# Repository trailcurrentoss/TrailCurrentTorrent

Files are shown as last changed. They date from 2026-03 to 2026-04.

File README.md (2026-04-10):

# TrailCurrent Torrent

<p align="center">
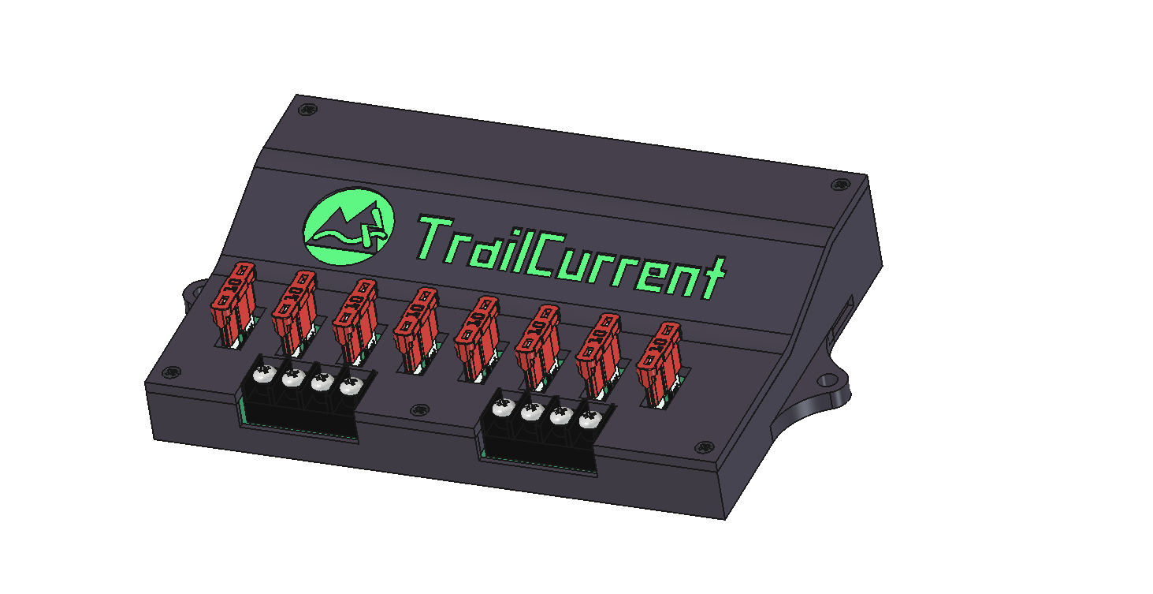
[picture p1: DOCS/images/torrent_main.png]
TrailCurrent Torrent
  
</p>

CAN-controlled 8-channel PWM power distribution module for vehicle lighting and accessory control with OTA firmware update capability and mDNS self-discovery. Up to 3 Torrent modules can operate on the same CAN bus, each with a unique address and CAN IDs. Part of the [TrailCurrent](https://trailcurrent.com) open-source vehicle platform.

## Hardware Overview

- **Microcontroller:** ESP32 (WROOM32)
- **Function:** 8-channel PWM lighting/accessory controller with CAN bus interface
- **Key Features:**
  - 8 independent MOSFET-driven PWM outputs (0-255 brightness)
  - CAN bus communication at 500 kbps
  - Up to 3 modules on the same bus via compile-time `TORRENT_ADDRESS` (0-2)
  - Individual and master on/off/brightness control
  - Animated light sequences (startup, interior, exterior)
  - Over-the-air (OTA) firmware updates via WiFi
  - mDNS self-discovery for automatic registration with Headwaters
  - WiFi credentials provisioned dynamically over CAN bus
  - Hierarchical PCB schematic design (5 sheets)

## Hardware Requirements

### Components

- **Microcontroller:** ESP32 development board
- **CAN Transceiver:** Vehicle CAN bus interface (TX: GPIO 15, RX: GPIO 13)
- **MOSFET Drivers:** 8 channels for PWM output switching
- **DIP Switches:** Configuration switches

### Pin Connections

**PWM Outputs:**

| GPIO | Function |
|---|---|
| 32 | Output 1 |
| 33 | Output 2 |
| 26 | Output 3 |
| 14 | Output 4 |
| 4 | Output 5 |
| 17 | Output 6 |
| 19 | Output 7 |
| 23 | Output 8 |

### KiCAD Library Dependencies

This project uses the consolidated [TrailCurrentKiCADLibraries](https://github.com/trailcurrentoss/TrailCurrentKiCADLibraries).

**Setup:**

```bash
# Clone the library
git clone git@github.com:trailcurrentoss/TrailCurrentKiCADLibraries.git

# Set environment variables (add to ~/.bashrc or ~/.zshrc)
export TRAILCURRENT_SYMBOL_DIR="/path/to/TrailCurrentKiCADLibraries/symbols"
export TRAILCURRENT_FOOTPRINT_DIR="/path/to/TrailCurrentKiCADLibraries/footprints"
export TRAILCURRENT_3DMODEL_DIR="/path/to/TrailCurrentKiCADLibraries/3d_models"
```

See [KICAD_ENVIRONMENT_SETUP.md](https://github.com/trailcurrentoss/TrailCurrentKiCADLibraries/blob/main/docs/KICAD_ENVIRONMENT_SETUP.md) in the library repository for detailed setup instructions.

## Opening the Project

1. **Set up environment variables** (see Library Dependencies above)
2. **Open KiCAD:**
   ```bash
   kicad EDA/trailcurrent-torrent.kicad_pro
   ```
3. **Verify libraries load** - All symbol and footprint libraries should resolve without errors
4. **View 3D models** - Open PCB and press `Alt+3` to view the 3D visualization

### Schematic Sheets

The design uses a hierarchical schematic with dedicated sheets:
- **Root** - Top-level connections
- **Power** - Power distribution and regulation
- **CAN** - CAN bus transceiver interface
- **MCU** - ESP32 microcontroller and support circuits
- **MOSFETs** - 8-channel MOSFET driver outputs
- **DIP Switch** - Configuration switches

## Firmware

Built with [ESP-IDF](https://docs.espressif.com/projects/esp-idf/en/latest/esp32/) (Espressif IoT Development Framework) targeting the ESP32.

### Prerequisites

Install ESP-IDF v5.x following the [official guide](https://docs.espressif.com/projects/esp-idf/en/latest/esp32/get-started/).

### Build and Flash

```bash
# Set up ESP-IDF environment
source ~/esp/v5.5.2/esp-idf/export.sh

# First time: set chip target
idf.py set-target esp32

# Build firmware (default address 0)
idf.py build

# Build for a specific module address (0-2)
idf.py build -DTORRENT_ADDRESS=1

# Flash and monitor (serial)
idf.py -p /dev/ttyUSB0 flash monitor
```

### Multi-Instance Addressing

Up to 3 Torrent modules can share the same CAN bus. Each module is built with a unique address that determines its CAN IDs:

```bash
idf.py build                      # Address 0 (default)
idf.py build -DTORRENT_ADDRESS=1  # Address 1
idf.py build -DTORRENT_ADDRESS=2  # Address 2
```

Each address produces a firmware binary with unique CAN IDs (see CAN Bus Protocol below). Flash each binary to a different ESP32. At boot, the module logs its address and CAN IDs for verification.

#### Building All Variants

Use `build-all.sh` to build all 3 address variants in a single run:

```bash
./build-all.sh
```

This produces two binaries per address — one for OTA updates, one for the web flasher:

| File | Contents | Used By |
|---|---|---|
| `build/torrent_addr{N}.bin` | Application image only | Headwaters OTA (`deploy.sh`, `ota.js`), direct `curl` uploads |
| `build/torrent_addr{N}_merged.bin` | Bootloader + partition table + OTA data + application | Web flasher (full flash at 0x0) |

The two binary types exist because OTA and the web flasher write to different targets. Headwaters OTA sends the binary to the device's `/ota` HTTP endpoint, which calls `esp_ota_write` to write it to a single app partition. That function validates the image as an application — a merged binary starts with the bootloader instead of an app header, so it would fail validation. The web flasher writes the entire flash contents starting at offset 0x0, so it needs all partitions combined into one file.

#### Creating a GitHub Release

After building all variants, attach all 6 binaries (3 app-only + 3 merged) as release assets:

```bash
git tag -a v1.0.0 -m "Firmware release v1.0.0"
git push origin v1.0.0

gh release create v1.0.0 \
  build/torrent_addr0.bin \
  build/torrent_addr1.bin \
  build/torrent_addr2.bin \
  build/torrent_addr0_merged.bin \
  build/torrent_addr1_merged.bin \
  build/torrent_addr2_merged.bin \
  --repo trailcurrentoss/TrailCurrentTorrent \
  --title "v1.0.0" \
  --notes "Firmware release v1.0.0"
```

Both the Headwaters deployment system and the web flasher pull from GitHub releases. The web flasher matches `_merged.bin` files by name for full-flash use. The Headwaters deployment system (`fetch-firmware.sh`) downloads the app-only `torrent_addr{N}.bin` files for OTA delivery.

### OTA Firmware Update

After initial serial flash, firmware can be updated over WiFi:

1. **Provision WiFi credentials** via CAN bus (message ID 0x01)
2. **Trigger OTA mode** via CAN bus (message ID 0x00 with device MAC bytes)
3. **Upload firmware** via HTTP — always use the app-only binary (`torrent_addr{N}.bin`), never the merged binary:
   ```bash
   curl -X POST http://esp32-XXYYZZ.local/ota --data-binary @build/torrent_addr0.bin
   ```

The device enters OTA mode for 3 minutes, starts an HTTP server, and advertises via mDNS. After a successful upload it reboots into the new firmware. Dual OTA partitions provide rollback safety.

### mDNS Self-Discovery

Modules register themselves with the Headwaters controller:

1. **Provision WiFi credentials** via CAN bus (message ID 0x01)
2. **Send discovery trigger** via CAN bus (message ID 0x02, broadcast)
3. Module joins WiFi and advertises a `_trailcurrent._tcp` mDNS service with metadata:
   - `type=torrent` — module type
   - `addr=0` — module address (0-2, from `TORRENT_ADDRESS` build flag)
   - `canid=0x1B` — CAN status message ID (varies by address)
   - `fw=1.0.0` — firmware version
4. Headwaters confirms registration by calling `GET /discovery/confirm`
5. Module tears down WiFi and returns to normal CAN operation

Discovery can be triggered again on subsequent CAN 0x02 broadcasts. A module that is already running a discovery session ignores additional triggers until the current session completes or times out (3 minutes).

### Logging

Firmware uses the ESP-IDF logging system (`ESP_LOGI`, `ESP_LOGW`, `ESP_LOGE`). Log output is available on the serial monitor at 115200 baud.

Log verbosity can be configured at build time via `idf.py menuconfig` under **Component config > Log output**.

**WiFi Credentials:**
- WiFi credentials are provisioned dynamically via CAN bus (Message ID 0x01)
- Credentials are stored in NVS (non-volatile storage) and persist across reboots
- For standalone testing, credentials can be set manually via NVS

### CAN Bus Protocol

CAN IDs are computed as `BASE + TORRENT_ADDRESS`. The table below shows base IDs and per-instance values.

**Receive (Bus → Module):**

| Base ID | Addr 0 | Addr 1 | Addr 2 | Description |
|---|---|---|---|---|
| — | 0x00 | 0x00 | 0x00 | OTA update trigger (3 bytes: last 3 MAC bytes for device targeting) |
| — | 0x01 | 0x01 | 0x01 | WiFi credential provisioning (chunked SSID/password protocol) |
| — | 0x02 | 0x02 | 0x02 | Discovery trigger (broadcast, no payload) |
| — | 0x04 | 0x04 | 0x04 | Version report on boot: `[mac3, mac4, mac5, major, minor, patch]` |
| 0x15 | 0x15 | 0x16 | 0x17 | Set brightness (byte 0 = channel 0-7, byte 1 = PWM value 0-255) |
| 0x18 | 0x18 | 0x19 | 0x1A | Toggle channel on/off (byte 0 = channel 0-7, 8=all off/on, 9=all on) |
| 0x33 | 0x33 | 0x34 | 0x35 | Trigger light sequence (byte 0: 0=interior, 1=exterior) |

**Transmit (Module → Bus):**

| Base ID | Addr 0 | Addr 1 | Addr 2 | Interval | Description |
|---|---|---|---|---|---|
| 0x1B | 0x1B | 0x1C | 0x1D | 33 ms (30 Hz) | Status report — current PWM values for all 8 channels (8 bytes) |

### WiFi Credential Provisioning Protocol

WiFi credentials are sent over CAN in chunks (max 6 payload bytes per CAN frame):

| Step | data[0] | Payload | Description |
|---|---|---|---|
| 1 | 0x01 | ssid_len, pass_len, ssid_chunks, pass_chunks | Start message |
| 2 | 0x02 | chunk_index, up to 6 bytes | SSID chunk |
| 3 | 0x03 | chunk_index, up to 6 bytes | Password chunk |
| 4 | 0x04 | XOR checksum | End/commit message |

All messages are sent on CAN ID 0x01. A 5-second timeout resets the state machine if the sequence is interrupted.

## Manufacturing

- **PCB Files:** Ready for fabrication via standard PCB services (JLCPCB, OSH Park, etc.)
- **BOM Generation:** Export BOM from KiCAD schematic (Tools > Generate BOM)
- **JLCPCB Assembly:** See [BOM_ASSEMBLY_WORKFLOW.md](https://github.com/trailcurrentoss/TrailCurrentKiCADLibraries/blob/main/tools/BOM_ASSEMBLY_WORKFLOW.md) for detailed assembly workflow

## Project Structure

```
├── EDA/                          # KiCAD hardware design files
│   ├── trailcurrent-torrent.kicad_pro
│   ├── trailcurrent-torrent.kicad_sch  # Root schematic
│   ├── can.kicad_sch             # CAN subsystem
│   ├── mcu.kicad_sch             # MCU subsystem
│   ├── power.kicad_sch           # Power subsystem
│   ├── mosfets.kicad_sch         # 8-channel MOSFET drivers
│   ├── dip_switch.kicad_sch      # Configuration switches
│   └── trailcurrent-torrent.kicad_pcb  # PCB layout
├── CAD/                          # FreeCAD case design and 3D models
│   ├── trailcurrent-torrent-case.FCStd
│   └── TrailCurrentTorrent.3mf
├── main/                         # ESP-IDF firmware source
│   ├── main.c                    # App entry, LEDC PWM, TWAI CAN task, light sequences
│   ├── ota.h / ota.c             # OTA updates, WiFi management, credential provisioning
│   ├── discovery.h / discovery.c # mDNS self-discovery and Headwaters registration
│   ├── CMakeLists.txt            # Component build config
│   └── idf_component.yml         # ESP-IDF component dependencies
├── partitions.csv                # ESP32 flash partition layout (dual OTA)
├── sdkconfig.defaults            # ESP-IDF build defaults
├── build-all.sh                  # Build all 3 address variants (addr 0-2)
└── CMakeLists.txt                # Root ESP-IDF project config
```

## License

MIT License - See LICENSE file for details.

This is open source hardware. You are free to use, modify, and distribute these designs under the terms of the MIT license.

## Contributing

Improvements and contributions are welcome! Please submit issues or pull requests.

## Support

For questions about:
- **KiCAD setup:** See [KICAD_ENVIRONMENT_SETUP.md](https://github.com/trailcurrentoss/TrailCurrentKiCADLibraries/blob/main/docs/KICAD_ENVIRONMENT_SETUP.md)
- **Assembly workflow:** See [BOM_ASSEMBLY_WORKFLOW.md](https://github.com/trailcurrentoss/TrailCurrentKiCADLibraries/blob/main/tools/BOM_ASSEMBLY_WORKFLOW.md)

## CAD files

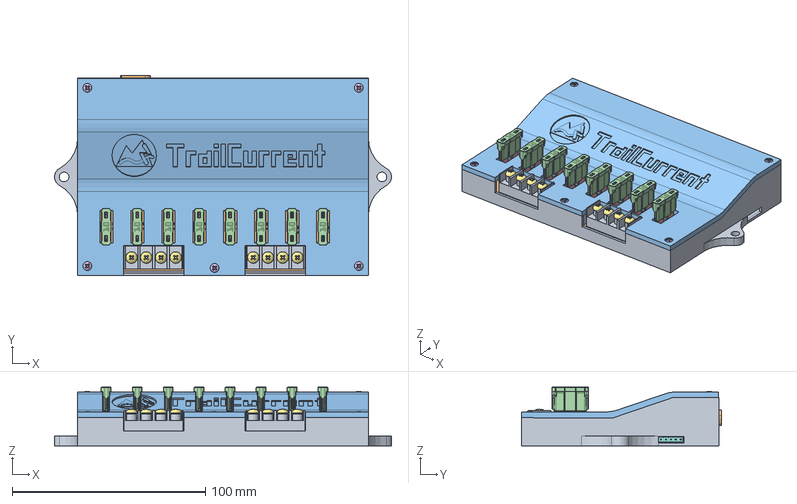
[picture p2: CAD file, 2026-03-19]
CAD/trailcurrent-torrent-case.FCStd
174.4 x 103.8 x 30.3 mm
BodyCaseBottom
Pcb_a65b
topPads_a65b
topTracks_a65b
botPads_a65b_cut
J5_Body_9aade6df98ed x 8
C4_C_1206_3216Metric_15ba0ad3e721 x 6
R8_R_1206_3216Metric_e07121ee4934 x 18
Q5_IRF4905STRLPBF_7185022933cc x 8
U5_DIP-4_W7.62mm_ebb48af450fe x 8
AP63203WU-7
AP63203WU-008
AP63203WU-009
AP63203WU-010
AP63203WU-011
AP63203WU-012
AP63203WU-013
AP63203WU-014
U1_ESP32-WROOM-32_2e14fae01c0c
U2_SOIC_8_39x49mm_P127mm_15ada4e996ee
FilletPin1
FilletPin2
J1_PinHeader_1x06_P254mm_Horizontal_2a81e018bd7b
J8_Body_1469dcacabcb x 2
XT60E-M
BodyContouredCover
ATOF Blade Fuse x 8
ATOF Blade Fuse001 x 8
2.5 mmx5-Screw x 5
3 mmx5-Screw x 8

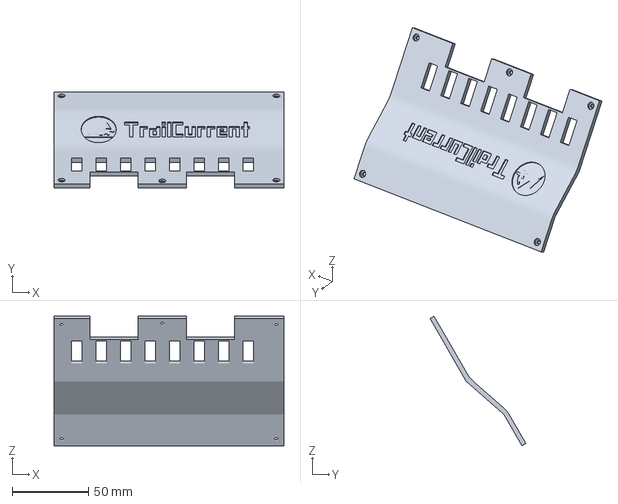
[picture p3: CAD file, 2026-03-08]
CAD/trailcurrent-torrent-case-BodyContouredCover.3mf
150.5 x 62.7 x 84.8 mm

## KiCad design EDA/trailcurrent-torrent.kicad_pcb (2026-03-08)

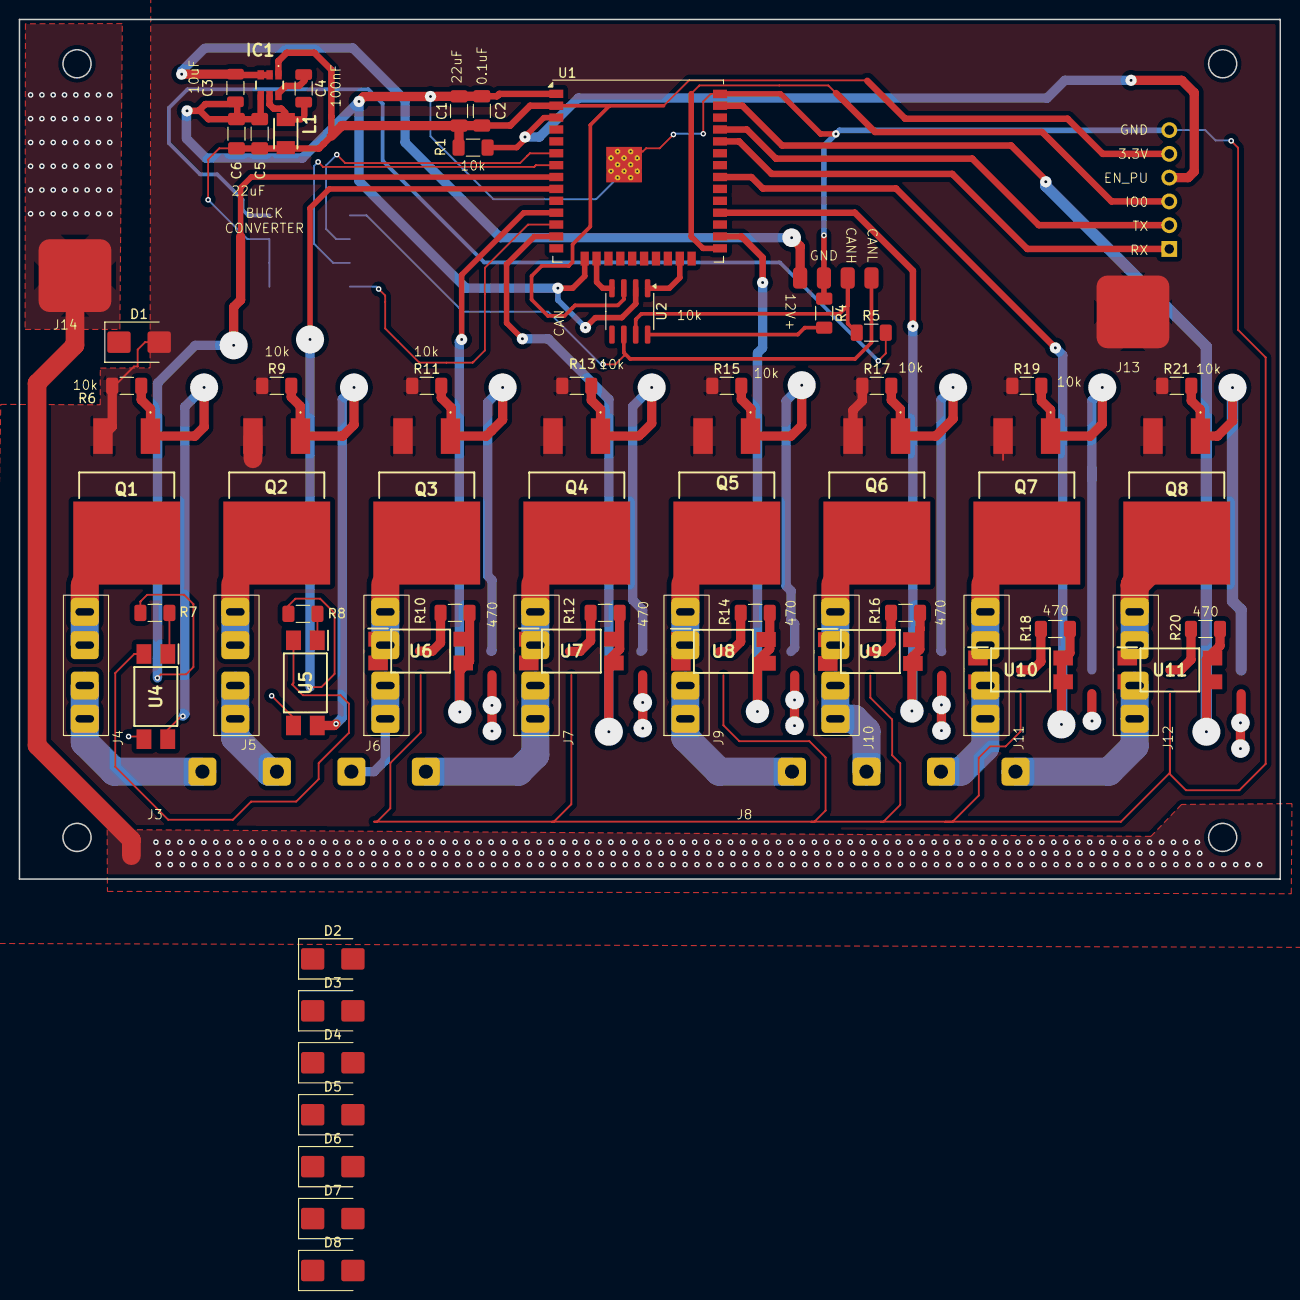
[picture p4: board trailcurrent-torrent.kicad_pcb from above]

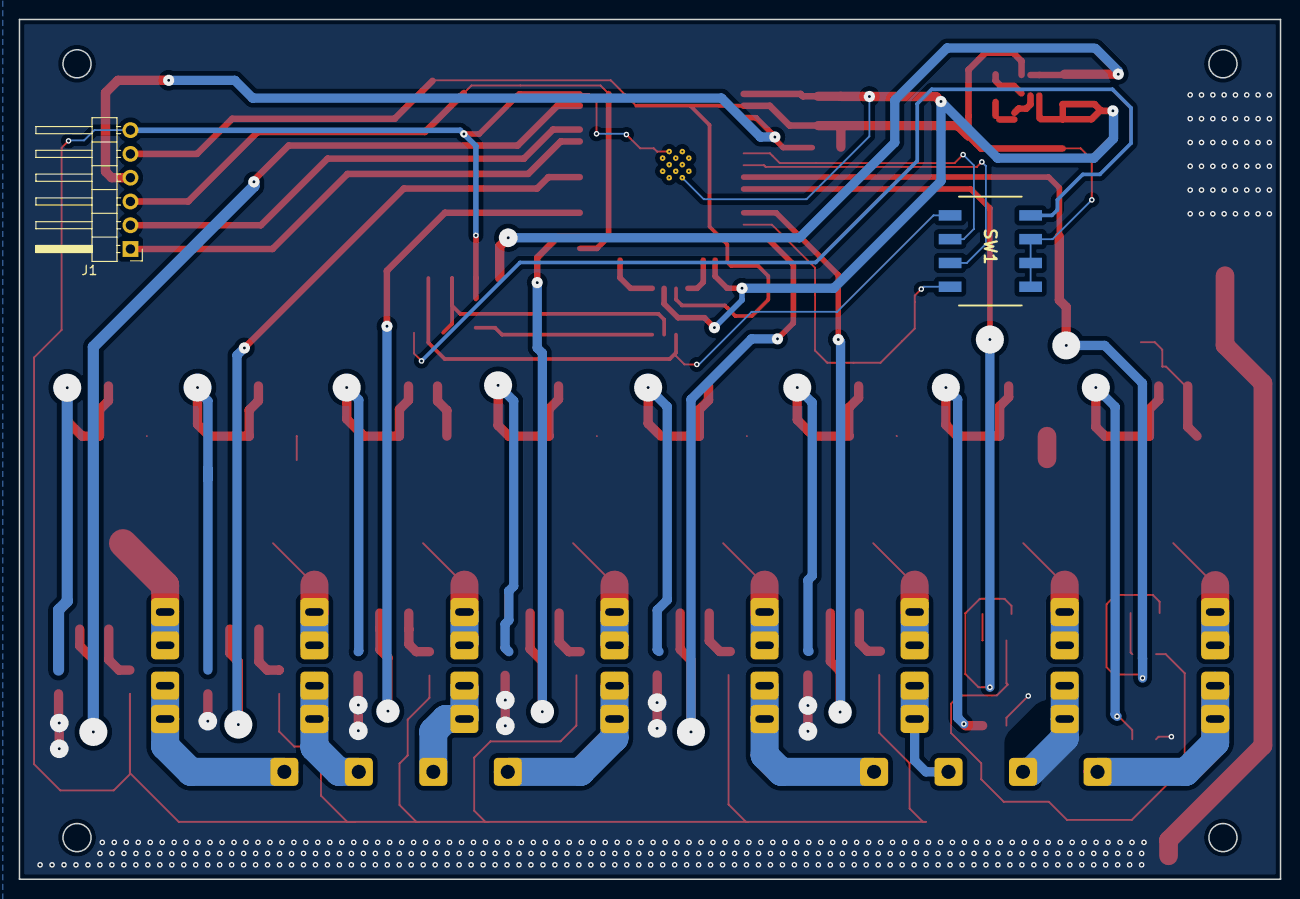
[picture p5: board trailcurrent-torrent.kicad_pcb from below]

Board: 2 copper layers, 134.7 x 91.9 mm, 68 parts (2 on the bottom side), 60 nets.

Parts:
C1, C5, C6: 22uF; C_1206_3216Metric_Pad1.33x1.80mm_HandSolder
C2: 0.1uF; C_1206_3216Metric_Pad1.33x1.80mm_HandSolder
C3: 10uF; C_1206_3216Metric
C4: 100nF; C_1206_3216Metric
D1, D2, D3, D4, D5, D6, D7, D8: SS54; D_SMB
IC1: AP63203WU-7; AP63203WU7
J1: Conn_01x06; PinHeader_1x06_P2.54mm_Horizontal
J2: Conn_01x04; CAN_PLUS_POWER
J3, J8: Conn_01x04; Screw_Terminal_1x04
J4, J5, J6, J7, J9, J10, J11, J12: Conn_01x04; Automotive_Fuse_Holder
J13, J14: Conn_01x01; TestPoint_7.77mmX7.77mm
L1: NLV32T-3R9J-EF (3.9uH); NLV32T-3R9J-EF
Q1, Q2, Q3, Q4, Q5, Q6, Q7, Q8: IRF4905STRLPBF
R1, R4, R6, R9, R11, R13, R15, R17, R19, R21: 10k; R_1206_3216Metric_Pad1.30x1.75mm_HandSolder
R5: 120; R_1206_3216Metric_Pad1.30x1.75mm_HandSolder
R7, R8, R10, R12, R14, R16, R18, R20: 470; R_1206_3216Metric_Pad1.30x1.75mm_HandSolder
SW1: SW_DIP_x04; SW_DIP_219-4LPST
U1: ESP32-WROOM-32; ESP32-WROOM-32U
U2: SN65HVD230; SOIC-8_3.9x4.9mm_P1.27mm
U4, U5, U6, U7, U8, U9, U10, U11: PC817; PC817X3CSP9F

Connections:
12V_OUT01: D1.1 (K), J4.3, J4.4, Q1.2 (D)
12V_OUT02: D2.1 (K), J5.3, J5.4, Q2.2 (D)
12V_OUT03: D3.1 (K), J6.3, J6.4, Q3.2 (D)
12V_OUT04: D4.1 (K), J7.3, J7.4, Q4.2 (D)
12V_OUT05: D5.1 (K), J9.3, J9.4, Q5.2 (D)
12V_OUT06: D6.1 (K), J10.3, J10.4, Q6.2 (D)
12V_OUT07: D7.1 (K), J11.3, J11.4, Q7.2 (D)
12V_OUT08: D8.1 (K), J12.3, J12.4, Q8.2 (D)
+3.3V: C1.1, C2.1, C5.1, C6.1, IC1.1 (FB), J1.5, L1.2, R1.1, SW1.5, SW1.6, SW1.7, U1.2 (VDD), U2.3 (VCC)
+12V: C3.1, IC1.2 (EN), IC1.3 (VIN), J2.1
+15V: D1.2 (A), D2.2 (A), D3.2 (A), D4.2 (A), D5.2 (A), D6.2 (A), D7.2 (A), D8.2 (A), J13.1, Q1.3 (S), Q2.3 (S), Q3.3 (S), Q4.3 (S), Q5.3 (S), Q6.3 (S), Q7.3 (S), Q8.3 (S), R6.1, R9.1, R11.1, R13.1, R15.1, R17.1, R19.1, R21.1
CANH: J2.3, R5.1, U2.7 (CANH)
CANL: J2.4, SW1.1, U2.6 (CANL)
CAN_RX: U1.16 (IO13), U2.4 (R)
CAN_TERM_CLOSED: R5.2, SW1.8
CAN_TX: U1.23 (IO15), U2.1 (D)
DEVICE01: R7.1, U1.8 (IO32)
DEVICE02: R8.1, U1.9 (IO33)
DEVICE03: R10.1, U1.11 (IO26)
DEVICE04: R12.1, U1.13 (IO14)
DEVICE05: R14.1, U1.26 (IO4)
DEVICE06: R16.1, U1.28 (IO17)
DEVICE07: R18.1, U1.31 (IO19)
DEVICE08: R20.1, U1.37 (IO23)
DEVICE_SELECTION01: SW1.2, U1.6 (IO34)
DEVICE_SELECTION02: SW1.3, U1.7 (IO35)
DEVICE_SELECTION03: SW1.4, U1.12 (IO27)
EN: J1.4, R1.2, U1.3 (EN)
ESP32_RX: J1.1, U1.34 (RXD0/IO3)
ESP32_TX: J1.2, U1.35 (TXD0/IO1)
GND: C1.2, C2.2, C3.2, C5.2, C6.2, IC1.4 (GND), J1.6, J2.2, R4.1, U1.1 (GND), U1.15 (GND), U1.38 (GND), U1.39 (GND), U2.2 (GND), U4.2, U5.2, U6.2, U7.2, U8.2, U9.2, U10.2, U11.2
GND1: J14.1, U4.3, U5.3, U6.3, U7.3, U8.3, U9.3, U10.3, U11.3
IO0: J1.3, U1.25 (IO0)
LOAD01: J3.1, J4.1, J4.2
LOAD02: J3.2, J5.1, J5.2
LOAD03: J3.3, J6.1, J6.2
LOAD04: J3.4, J7.1, J7.2
LOAD05: J8.1, J9.1, J9.2
LOAD06: J8.2, J10.1, J10.2
LOAD07: J8.3, J11.1, J11.2
LOAD08: J8.4, J12.1, J12.2
unnamed: C4.1, IC1.6 (BST)
unnamed: C4.2, IC1.5 (SW), L1.1
unnamed: Q1.1 (G), R6.2, U4.4
unnamed: Q2.1 (G), R9.2, U5.4
unnamed: Q3.1 (G), R11.2, U6.4
unnamed: Q4.1 (G), R13.2, U7.4
unnamed: Q5.1 (G), R15.2, U8.4
unnamed: Q6.1 (G), R17.2, U9.4
unnamed: Q7.1 (G), R19.2, U10.4
unnamed: Q8.1 (G), R21.2, U11.4
unnamed: R7.2, U4.1
unnamed: R8.2, U5.1
unnamed: R10.2, U6.1
unnamed: R12.2, U7.1
unnamed: R14.2, U8.1
unnamed: R16.2, U9.1
unnamed: R18.2, U10.1
unnamed: R20.2, U11.1
unnamed: R4.2, U2.8 (Rs)

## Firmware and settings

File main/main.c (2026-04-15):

#include "freertos/FreeRTOS.h"
#include "freertos/task.h"
#include "esp_log.h"
#include "wifi_config.h"
#include "ota.h"
#include "discovery.h"
#include "can_handler.h"
#include "pwm_output.h"

static const char *TAG = "torrent";

#ifndef TORRENT_ADDRESS
#define TORRENT_ADDRESS 0
#endif

void app_main(void)
{
    ESP_LOGI(TAG, "=== TrailCurrent Torrent (addr %d) ===", TORRENT_ADDRESS);
    ESP_LOGI(TAG, "8-Channel PWM Lighting Control Module");

    wifi_config_init();

    char ssid[33], password[64];
    if (wifi_config_load(ssid, sizeof(ssid), password, sizeof(password))) {
        ESP_LOGI(TAG, "WiFi credentials loaded (SSID: %s)", ssid);
    } else {
        ESP_LOGW(TAG, "No WiFi credentials — provision via CAN ID 0x01");
    }

    ota_init();
    discovery_init();

    ESP_LOGI(TAG, "Hostname: %s", wifi_config_get_hostname());

    pwm_output_init();

    ESP_ERROR_CHECK(can_handler_init());

    ESP_LOGI(TAG, "=== Setup Complete ===");

    xTaskCreatePinnedToCore(can_handler_task, "can_task", 4096, NULL, 5, NULL, 1);

    while (1) {
        vTaskDelay(pdMS_TO_TICKS(1000));
    }
}

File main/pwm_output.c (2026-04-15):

#include "pwm_output.h"

#include "driver/ledc.h"
#include "esp_log.h"
#include "freertos/FreeRTOS.h"
#include "freertos/task.h"

static const char *TAG = "pwm";

// =============================================================================
// Pin and LEDC configuration
// =============================================================================

static const int OUTPUT_PINS[NUM_OUTPUTS] = {
    32,  // OUTPUT01
    33,  // OUTPUT02
    26,  // OUTPUT03
    14,  // OUTPUT04
     4,  // OUTPUT05
    17,  // OUTPUT06
    19,  // OUTPUT07
    23,  // OUTPUT08
};

#define LEDC_TIMER      LEDC_TIMER_0
#define LEDC_MODE       LEDC_LOW_SPEED_MODE
#define LEDC_DUTY_RES   LEDC_TIMER_8_BIT   // 0-255
#define LEDC_FREQUENCY  5000               // 5 kHz

// =============================================================================
// Internal state
// =============================================================================

static uint8_t s_values[NUM_OUTPUTS] = {0};

// =============================================================================
// Public API
// =============================================================================

void pwm_output_init(void)
{
    ledc_timer_config_t timer_cfg = {
        .speed_mode      = LEDC_MODE,
        .duty_resolution = LEDC_DUTY_RES,
        .timer_num       = LEDC_TIMER,
        .freq_hz         = LEDC_FREQUENCY,
        .clk_cfg         = LEDC_AUTO_CLK,
    };
    ledc_timer_config(&timer_cfg);

    for (int i = 0; i < NUM_OUTPUTS; i++) {
        ledc_channel_config_t ch_cfg = {
            .gpio_num   = OUTPUT_PINS[i],
            .speed_mode = LEDC_MODE,
            .channel    = (ledc_channel_t)i,
            .timer_sel  = LEDC_TIMER,
            .duty       = 0,
            .hpoint     = 0,
        };
        ledc_channel_config(&ch_cfg);
    }

    ESP_LOGI(TAG, "LEDC PWM initialized: %d channels at %d Hz", NUM_OUTPUTS, LEDC_FREQUENCY);
}

void pwm_set(int channel, uint8_t duty)
{
    if (channel < 0 || channel >= NUM_OUTPUTS) return;
    s_values[channel] = duty;
    ledc_set_duty(LEDC_MODE, (ledc_channel_t)channel, duty);
    ledc_update_duty(LEDC_MODE, (ledc_channel_t)channel);
}

void pwm_set_all(uint8_t duty)
{
    for (int i = 0; i < NUM_OUTPUTS; i++) {
        pwm_set(i, duty);
    }
}

uint8_t pwm_get(int channel)
{
    if (channel < 0 || channel >= NUM_OUTPUTS) return 0;
    return s_values[channel];
}

void pwm_get_all(uint8_t *out)
{
    for (int i = 0; i < NUM_OUTPUTS; i++) {
        out[i] = s_values[i];
    }
}

void pwm_refresh_all(void)
{
    for (int i = 0; i < NUM_OUTPUTS; i++) {
        ledc_set_duty(LEDC_MODE, (ledc_channel_t)i, s_values[i]);
        ledc_update_duty(LEDC_MODE, (ledc_channel_t)i);
    }
}

// =============================================================================
// Light sequences (blocking)
// =============================================================================

void light_sequence_startup(void)
{
    pwm_set_all(0);
    vTaskDelay(pdMS_TO_TICKS(500));

    // Section 1: Progressive wave
    for (int wave = 0; wave < 3; wave++) {
        for (int i = 0; i < NUM_OUTPUTS; i++) {
            pwm_set(i, 255);
            vTaskDelay(pdMS_TO_TICKS(100));
            pwm_set(i, 0);
        }
    }
    vTaskDelay(pdMS_TO_TICKS(300));

    // Section 2: All lights pulse together
    for (int pulse = 0; pulse < 4; pulse++) {
        for (int v = 0; v <= 255; v += 25) {
            pwm_set_all((uint8_t)v);
            vTaskDelay(pdMS_TO_TICKS(30));
        }
        for (int v = 255; v >= 0; v -= 25) {
            pwm_set_all((uint8_t)v);
            vTaskDelay(pdMS_TO_TICKS(30));
        }
    }
    vTaskDelay(pdMS_TO_TICKS(300));

    // Section 3: Alternating pattern
    for (int alt = 0; alt < 5; alt++) {
        for (int i = 0; i < NUM_OUTPUTS; i++) {
            pwm_set(i, (i % 2 == 0) ? 255 : 0);
        }
        vTaskDelay(pdMS_TO_TICKS(200));
        for (int i = 0; i < NUM_OUTPUTS; i++) {
            pwm_set(i, (i % 2 == 1) ? 255 : 0);
        }
        vTaskDelay(pdMS_TO_TICKS(200));
        pwm_set_all(0);
        vTaskDelay(pdMS_TO_TICKS(100));
    }
    vTaskDelay(pdMS_TO_TICKS(300));

    // Section 4: Spiral pattern
    for (int spiral = 0; spiral < 3; spiral++) {
        for (int i = 0; i < NUM_OUTPUTS; i++) {
            pwm_set(i, 255);
            vTaskDelay(pdMS_TO_TICKS(80));
        }
        vTaskDelay(pdMS_TO_TICKS(200));
        for (int i = NUM_OUTPUTS - 1; i >= 0; i--) {
            pwm_set(i, 0);
            vTaskDelay(pdMS_TO_TICKS(80));
        }
        vTaskDelay(pdMS_TO_TICKS(200));
    }
    vTaskDelay(pdMS_TO_TICKS(300));

    // Section 5: Rapid flash finale
    for (int flash = 0; flash < 8; flash++) {
        pwm_set_all(255);
        vTaskDelay(pdMS_TO_TICKS(200));
        pwm_set_all(0);
        vTaskDelay(pdMS_TO_TICKS(200));
    }

    pwm_set_all(0);
}

void light_sequence_interior(void)
{
    // Channels 4-7 (OUTPUT05-OUTPUT08)
    for (int i = 4; i < 8; i++) pwm_set(i, 0);

    // Fade in
    for (int v = 0; v <= 255; v++) {
        for (int i = 4; i < 8; i++) pwm_set(i, (uint8_t)v);
        vTaskDelay(pdMS_TO_TICKS(10));
    }
    // Fade out
    for (int v = 255; v >= 0; v--) {
        for (int i = 4; i < 8; i++) pwm_set(i, (uint8_t)v);
        vTaskDelay(pdMS_TO_TICKS(10));
    }

    // Rotating pattern
    for (int cycle = 0; cycle <= 30; cycle++) {
        for (int step = 0; step < 4; step++) {
            for (int i = 4; i < 8; i++) {
                pwm_set(i, (i - 4 == step) ? 255 : 0);
            }
            vTaskDelay(pdMS_TO_TICKS(60));
        }
        for (int step = 2; step >= 1; step--) {
            for (int i = 4; i < 8; i++) {
                pwm_set(i, (i - 4 == step) ? 255 : 0);
            }
            vTaskDelay(pdMS_TO_TICKS(60));
        }
        pwm_set(7, 255);
        for (int i = 4; i < 7; i++) pwm_set(i, 0);
        vTaskDelay(pdMS_TO_TICKS(60));
    }
    for (int i = 4; i < 8; i++) pwm_set(i, 0);
}

void light_sequence_exterior(void)
{
    // Channels 2-3 (OUTPUT03-OUTPUT04)
    pwm_set(2, 0);
    pwm_set(3, 0);

    // Fade in
    for (int v = 0; v <= 255; v++) {
        pwm_set(2, (uint8_t)v);
        pwm_set(3, (uint8_t)v);
        vTaskDelay(pdMS_TO_TICKS(10));
    }
    // Fade out
    for (int v = 255; v >= 0; v--) {
        pwm_set(2, (uint8_t)v);
        pwm_set(3, (uint8_t)v);
        vTaskDelay(pdMS_TO_TICKS(10));
    }

    // Alternating pattern
    for (int cycle = 0; cycle <= 30; cycle++) {
        pwm_set(2, 255);
        pwm_set(3, 0);
        vTaskDelay(pdMS_TO_TICKS(250));
        pwm_set(2, 0);
        pwm_set(3, 255);
        vTaskDelay(pdMS_TO_TICKS(250));
    }
    pwm_set(2, 0);
    pwm_set(3, 0);
}

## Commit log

2026-03-19 Adding assembled image to readme
    [trailcurrent-torrent-case.FCStd]
2026-03-26 Moving to ESP-IDF
    [partitions.csv]
2026-03-28 Fixing issue with CAN Bus stops responding when discovery happens
    [main.c]
2026-04-15 Aligning CAN Bus implementation with Switchback for more robust handling of varios edge cases.
2026-04-15 Working on pattern that will be repeated for all CAN Bus scenarios
